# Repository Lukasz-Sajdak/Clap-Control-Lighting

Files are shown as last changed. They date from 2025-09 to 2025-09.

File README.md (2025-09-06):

# Clap Control Lighting
## Description

Clap Control Lighting is a hardware project that switches lights on and off by detecting claps. The circuit is based on an envelope detector connected to a microphone, simulated in LTSpice, and implemented on a compact PCB to drive a relay.

## Schematic


## PCB


## LTSpice Simulation


The envelope detector was simulated in LTSpice to verify its behavior before PCB implementation.

# Features

- Envelope detector for clap sound detection
- LTSpice simulation of the envelope detector
- Microphone input for simple acoustic control
- Relay output to drive a light or other load
- Compact PCB ready for manufacturing

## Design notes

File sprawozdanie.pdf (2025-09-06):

1

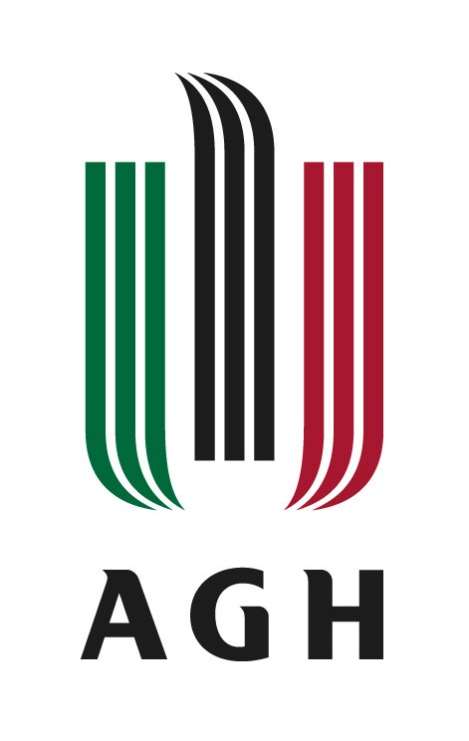
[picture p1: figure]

09.06.2025

## Projektowanie układów elektronicznych

Prowadzący: dr hab. inż. Cezary Worek

# Sprawozdanie

# Bezprzewodowy czujnik sterowania oświetleniem – ultra low-power

Autor:
Łukasz Sajdak

2

## Spis treści

3

### 1. Cel projektu

Celem projektu było stworzenie czujnika sterowania oświetleniem, którego działanie jest oparte na wykryciu klaśnięcia użytkownika. System wykorzystuje mikrokontroler, mikrofon MEMS oraz technologię Bluetooth Low Energy (BLE), umożliwiając efektywne zarządzanie zużyciem energii i detekcję dźwięku w trybie ultra-low power.

### 2. Założenia projektowe

- Analogowy tor wejściowy audio - wstępna obróbka sygnału dźwiękowego.
- Obróbka sygnału na mikrokontrolerze - mikrokontroler powinien umożliwiać efektywną cyfrową analizę sygnału audio w celu wykrywania charakterystycznych wzorców dźwiękowych.
- Interfejs: bezprzewodowy BLE - System musi posiadać energooszczędny interfejs komunikacyjny BLE.
- Zasilanie: Ultra Low Power - Całość urządzenia powinna być zoptymalizowana pod kątem minimalnego zużycia energii, co pozwoli na długotrwałą pracę na baterii.
- Projekt komercyjny - Urządzenie musi być dostosowane do codziennego użytku w warunkach domowych.

### 3. Zasada działania

### 1. Urządzenie znajduje się w trybie głębokiego uśpienia (deep sleep), minimalizując

zużycie energii.

### 2. Mikrofon MEMS z funkcją Wake-on-Sound nasłuchuje otoczenia i po wykryciu sygnału

akustycznego aktywuje mikrokontroler, przechodząc jednocześnie w tryb normalnej pracy.

### 3. Sygnał zostaje wzmocniony, przefiltrowany w analogowym torze audio i przekazany

przez detektor obwiedni do ADC.

### 4. Mikrokontroler pobiera dane z przetwornika ADC i analizuje sygnał w celu rozpoznania

charakterystycznego wzorca klaśnięcia.

### 5. Po pozytywnej detekcji wysyłana jest komenda sterująca przez interfejs Bluetooth Low

Energy (BLE).

### 6. Po zakończeniu transmisji system automatycznie przechodzi z powrotem do trybu

uśpienia, oczekując na kolejne zdarzenie dźwiękowe.

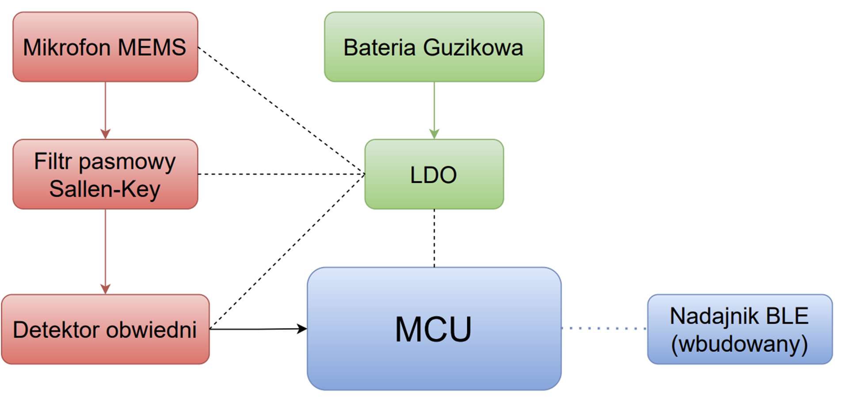
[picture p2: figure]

4

### 4. Schemat blokowy

Poniżej przedstawiono ogólny schemat blokowy systemu, który ilustruje połączenia między wszystkimi kluczowymi komponentami projektu czujnika sterowania oświetleniem (Rys.1).

Rys. 1 Schemat blokowy projektu

### 4.1 Dobór Komponentów

Dobór komponentów:
- mikrokontroler Seeed Xiao BLE nRF52840 - mikrokontroler z wbudowanym BLE i bardzo niskim zużyciem energii.
- mikrofon MEMS VM1010 - niskoszumny mikrofon MEMS z funkcją Wake-on-Sound.
- stabilizator TPS78333 - LDO 3.3V o bardzo małym prądzie spoczynkowym.
- TLV9044 - czterokanałowy wzmacniacz operacyjny
- bateria Li-Ion 3,7V - zasilanie

Kluczowe elementy:

Mikrokontroler Seeed XIAO nRF52840 odpowiada za cyfrowe przetwarzanie sygnałów pochodzących z mikrofonu, w tym analizę próbek audio w celu wykrycia wzorca klaśnięcia, a także za zarządzanie komunikacją bezprzewodową w standardzie Bluetooth Low Energy (BLE), umożliwiając przesyłanie komend do innych urządzeń.

Mikrofon MEMS VM1010 pełni rolę czujnika akustycznego – jego funkcja Wake-on-Sound pozwala wykryć dźwięk i aktywować system z trybu uśpienia, co znacząco ogranicza zużycie energii.

Detektor obwiedni – został zrealizowany w oparciu o układ diodowy, który cechuje się niskim poborem mocy, co jest zgodne z założeniem minimalizacji zużycia energii. Choć tego typu detektor może wprowadzać pewne zniekształcenia sygnału, okazał się wystarczający do klaśnięcia.

5

### 4.2 Software

Detekcja klaśnięcia:

### 1. Tryb czuwania (Sleep + Wake-on-Sound)

Mikrokontroler przez większość czasu pozostaje w trybie głębokiego uśpienia (deep sleep). Wybudzany jest jedynie wtedy, gdy mikrofon MEMS wykryje impuls akustyczny o odpowiednim poziomie, uruchamiając funkcję Wake-on-Sound.

### 2. Pobieranie próbek z przetwornika ADC

Po wybudzeniu system rozpoczyna akwizycję sygnału za pomocą wbudowanego przetwornika analogowo-cyfrowego.

### 3. Analiza sygnału i detekcja wzorca klaśnięcia

Pobrane dane są analizowane pod kątem amplitudy, kształtu i czasu trwania impulsu. Jeśli sygnał spełnia warunki charakterystyczne dla klaśnięcia, zostaje rozpoznane zdarzenie.

### 4. Transmisja komendy przez BLE

Po wykryciu klaśnięcia mikrokontroler inicjuje transmisję danych przez interfejs Bluetooth Low Energy, wysyłając komendę sterującą (np. "toggle światło") do odbiornika.

### 5. Powrót do trybu uśpienia

Po zakończeniu transmisji system automatycznie przechodzi z powrotem w tryb głębokiego uśpienia, oczekując na kolejne wybudzenie przez mikrofon.

### 5. Schemat ideowy

Poniżej przedstawiono szczegółowy schemat ideowy (Rys. 2), który prezentuje połączenia między mikrofonem, analogowym torem audio, mikrokontrolerem i układem zasilania.

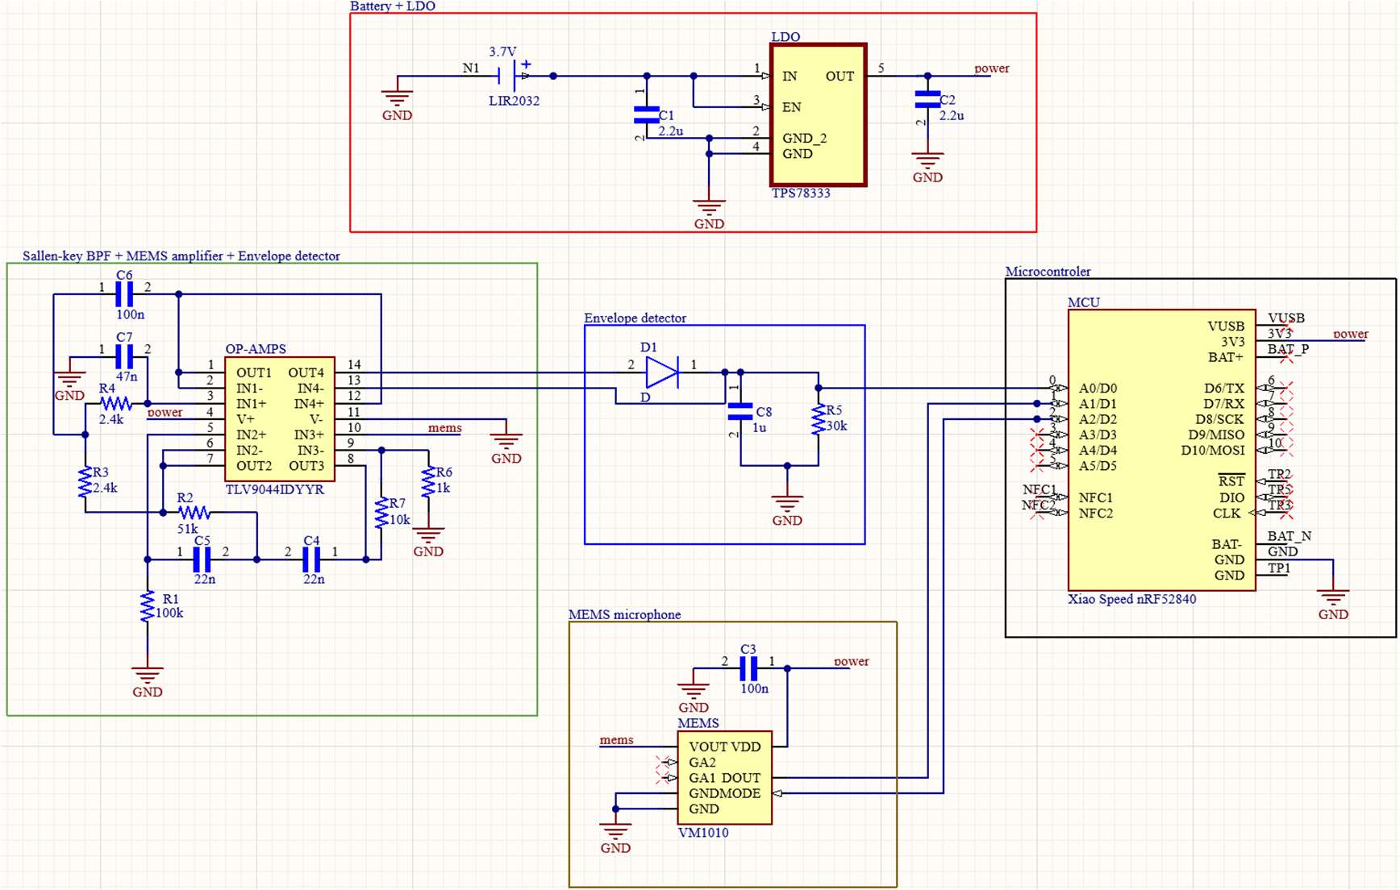
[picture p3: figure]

Rys. 2 Schemat Ideowy

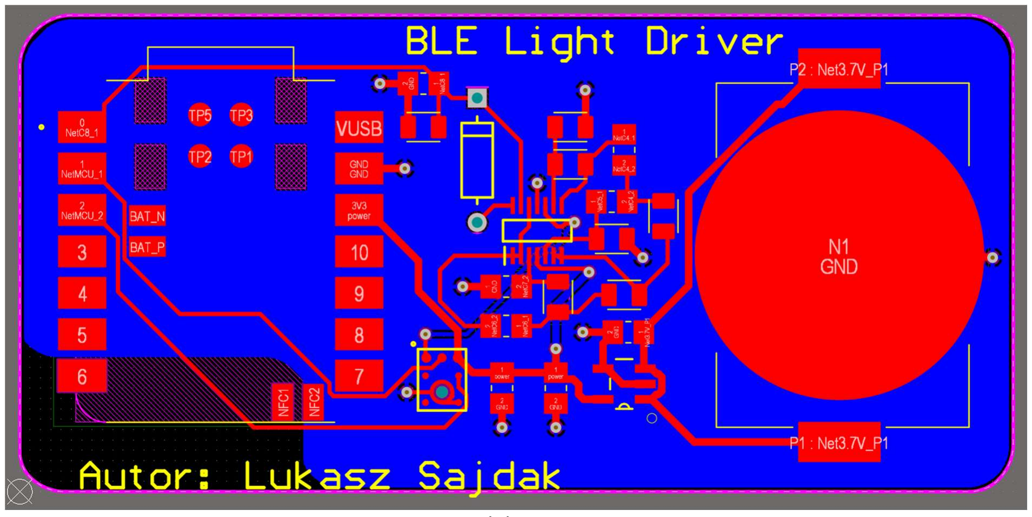
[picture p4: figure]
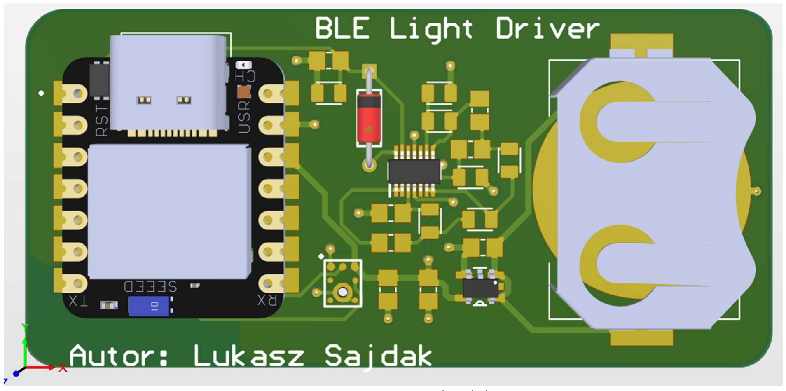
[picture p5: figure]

6

### 6. Projekt PCB

Projekt PCB uwzględnia szersze ścieżki zasilania o szerokości 0,5 mm w celu minimalizacji spadków napięcia i zapewnienia stabilności pracy układu. Pod anteną BLE celowo nie umieszczono pola masy, aby uniknąć zakłóceń i poprawić parametry transmisji bezprzewodowej. Wszystkie komponenty zostały rozmieszczone możliwie blisko siebie, co pozwoliło na zmniejszenie wymiarów płytki i ograniczenie długości ścieżek sygnałowych. Poniżej przedstawiono graficzne wizualizacje zaprojektowanej płytki PCB. (Rys. 3-5).

Rys. 3 Widok warstw PCB.

Rys. 4 Widok 3D PCB (przód).

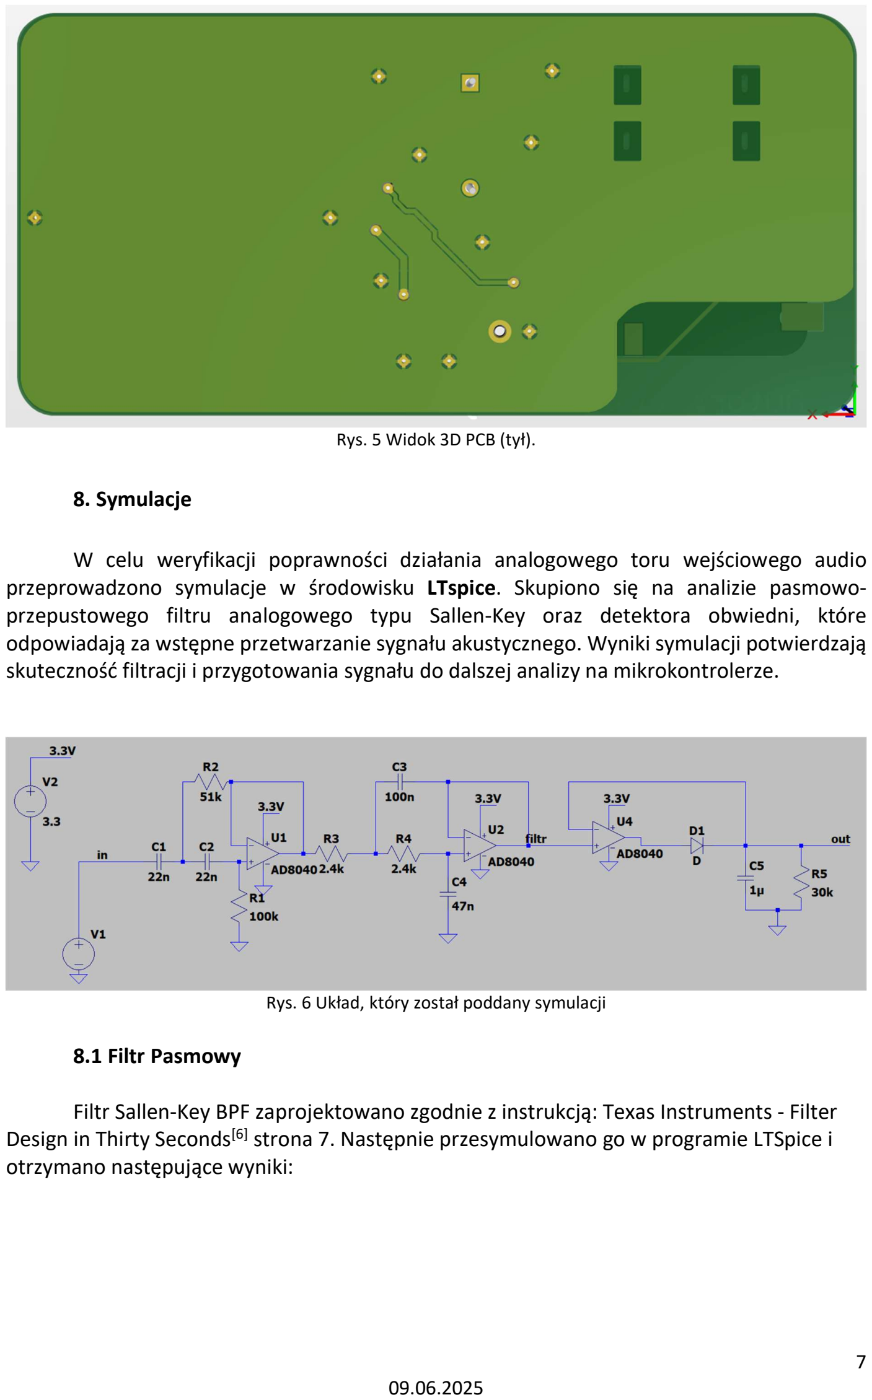
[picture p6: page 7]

7

Rys. 5 Widok 3D PCB (tył).

### 8. Symulacje

W celu weryfikacji poprawności działania analogowego toru wejściowego audio przeprowadzono symulacje w środowisku LTspice. Skupiono się na analizie pasmowo-przepustowego filtru analogowego typu Sallen-Key oraz detektora obwiedni, które odpowiadają za wstępne przetwarzanie sygnału akustycznego. Wyniki symulacji potwierdzają skuteczność filtracji i przygotowania sygnału do dalszej analizy na mikrokontrolerze.

Rys. 6 Układ, który został poddany symulacji

### 8.1 Filtr Pasmowy

Filtr Sallen-Key BPF zaprojektowano zgodnie z instrukcją: Texas Instruments - Filter Design in Thirty Seconds[6] strona 7. Następnie przesymulowano go w programie LTSpice i otrzymano następujące wyniki:

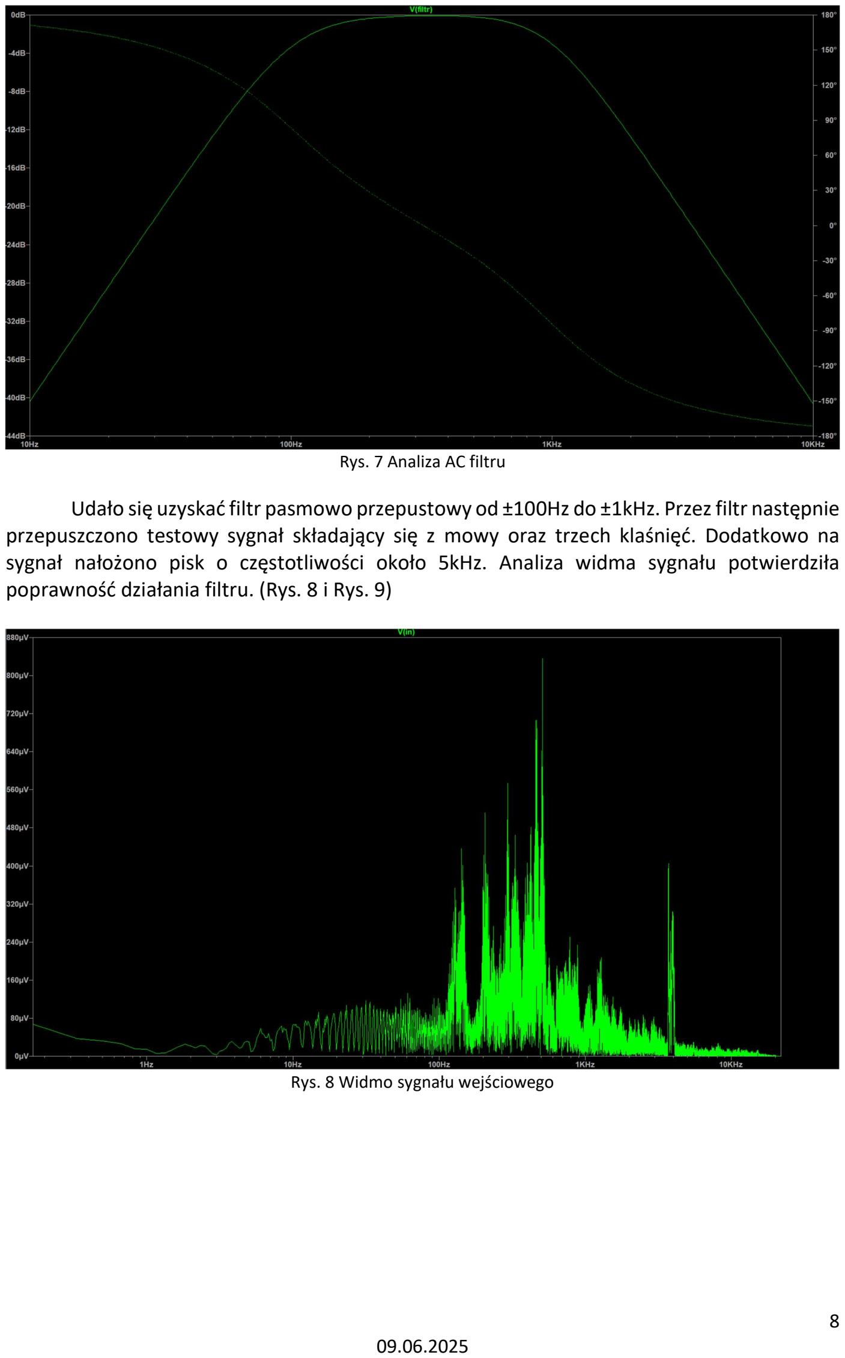
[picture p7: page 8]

8

Rys. 7 Analiza AC filtru
Udało się uzyskać filtr pasmowo przepustowy od ±100Hz do ±1kHz. Przez filtr następnie przepuszczono testowy sygnał składający się z mowy oraz trzech klaśnięć. Dodatkowo na sygnał nałożono pisk o częstotliwości około 5kHz. Analiza widma sygnału potwierdziła poprawność działania filtru. (Rys. 8 i Rys. 9)

Rys. 8 Widmo sygnału wejściowego

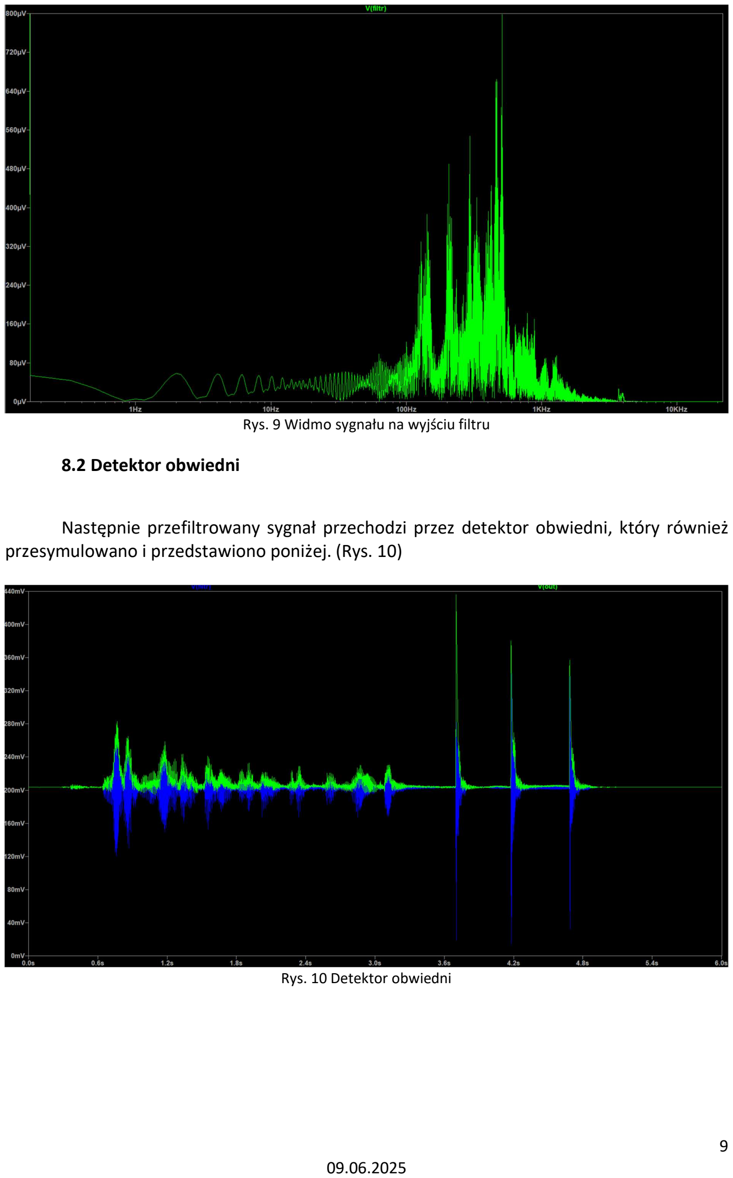
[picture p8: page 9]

9

Rys. 9 Widmo sygnału na wyjściu filtru

### 8.2 Detektor obwiedni

Następnie przefiltrowany sygnał przechodzi przez detektor obwiedni, który również przesymulowano i przedstawiono poniżej. (Rys. 10)

Rys. 10 Detektor obwiedni

10

### 9. Wycena

Designator | Value/Type | Symbol | Ilość | Cena/szt | Cena | Dostawca | Link
3.7V | LIR2032 | BAT-HLD-001-TR | 1 | 2,29 zł | 2,29 zł | DigiKey | Link
C1, C2 | 2.2u | CL21B222JBANNNC | 2 | 0,08 zł | 0,17 zł | DigiKey | Link
C3, C6 | 100n | CL21B104KCFNNNE | 2 | 0,04 zł | 0,07 zł | DigiKey | Link
C4, C5 | 22n | CL21B223KBANFNC | 2 | 0,07 zł | 0,14 zł | DigiKey | Link
C7 | 47n | CL21B473KBCNNNC | 1 | 0,07 zł | 0,07 zł | DigiKey | Link
C8 | 1u | CL21B105KBFNNNE | 1 | 0,06 zł | 0,06 zł | DigiKey | Link
D1 | BAT46 | BAT46 | 1 | 0,31 zł | 0,31 zł | DigiKey | Link
LDO | TPS783x | TPS78333 | 1 | 0,55 zł | 0,55 zł | DigiKey | Link
MCU | nRF52840 | Xiao Speed nRF52840 | 1 | 28,74 zł | 28,74 zł | SpeedStudio | Link
MEMS | VM1010 | Vesper VM1010 | 1 | 6,07 zł | 6,07 zł | xonelec | Link
OP-AMPS | TLV9044 | TLV9044IDYYR | 1 | 2,24 zł | 2,24 zł | DigiKey | Link
R1 | 100k | RG2012P-104-B-T5 | 1 | 0,21 zł | 0,21 zł | DigiKey | Link
R2 | 51k | RC0805JR-0751KL | 1 | 0,03 zł | 0,03 zł | DigiKey | Link
R3, R4 | 2.4k | RMCF0805JT2K40 | 2 | 0,04 zł | 0,08 zł | DigiKey | Link
R5 | 30k | RMCF0805FT30K0 | 1 | 0,04 zł | 0,04 zł | DigiKey | Link
R6 | 1k | RG2012P-102-B-T5 | 1 | 0,21 zł | 0,21 zł | DigiKey | Link
R7 | 10k | RR1220P-103-D | 1 | 0,10 zł | 0,10 zł | DigiKey | Link

Założony nakład: 100 szt
Koszt jednej sztuki: 41,37zł
Koszt całkowity: 4136,57zł

11

### 10. Podsumowanie

Projekt czujnika klaśnięcia został zrealizowany jako jako koncepcyjny prototyp, spełniający założenia energooszczędności, kompaktowości oraz możliwości bezprzewodowej integracji. Udało się skutecznie połączyć analogowy tor przetwarzania sygnału audio z cyfrową analizą w mikrokontrolerze i transmisją BLE, przy zachowaniu bardzo niskiego poboru mocy. System wykrywa pojedyncze klaśnięcie i może być wykorzystywany do sterowania oświetleniem lub innymi elementami systemów smart home.

W przyszłości możliwa jest rozbudowa projektu o:
- detekcję sekwencji klaśnięć
- integrację z aplikacją mobilną
- możliwość sterowania wieloma urządzeniami na podstawie ustalonych wzorców dźwiękowych.

### 11. Bibliografia

[1] Dokumentacja mikrofonu VM1010
[2] Dokumentacja Seeed Xiao BLE nRF52840
[3] Dokumentacja nRF52840
[4] Dokumentacja TPS78333
[5] Dokumentacja TLV9044
[5] Texas Instruments – Analysis of the Sallen-Key Architecture [https://www.ti.com/lit/an/sloa024b/sloa024b.pdf]
[6] Texas Instruments - Filter Design in Thirty Seconds [https://www.vyssotski.ch/BasicsOfInstrumentation/FilterDesignIn30Seconds.pdf]
[7] Detektor obwiedni [http://old.zseii.edu.pl/archive/dydaktyka/elektronika/ue/06.html]
